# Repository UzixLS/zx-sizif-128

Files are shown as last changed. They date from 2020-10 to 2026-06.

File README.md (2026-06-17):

## Sizif-128

Easy-to-build minimalistic ZX Spectrum clone.

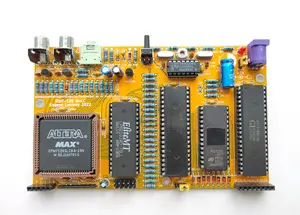
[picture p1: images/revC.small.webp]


[(some random photos)](https://cloud.err200.net/index.php/s/73TR85tYZkMm8Ax?path=%2Fsizif-128)

Specifications:
- CPLD EPM7128SLC84 (128 macrocells)
- Z80 3.5 MHz
- 128K RAM
- AY-3-8910 (YM2149) mono sound
- Pentagon timings
- PAL encoder in CPLD (CRT TVs preferred)
- Intended to build on 9x15 prototyping board, but may be built on manufactured PCB

To modify and compile CPLD firmware you need Quartus 13.0sp1.
To modify schematic and pcb you need Kicad 6 or newer.

### Changelog
* Rev.A - first release. Please note the [errata](pcb/rev.A/ERRATA.txt).
* Rev.B - experimental PCB
    * 74HCU04-based tape input
    * added power LED
    * added reset button
    * removed NMI button
    * C20 replaced by variable variant to tune PAL color signal
* Rev.C
    * 74HCU04-based tape input reverted back to transistor-based
    * unused U6 inputs has been grounded
    * video circuit has been tuned for best colors
    * all pcb tracks are fancy now ;)
* Rev.C1
    * improve tape input sensitivity (thanks to SerOne from zx-pk forum)

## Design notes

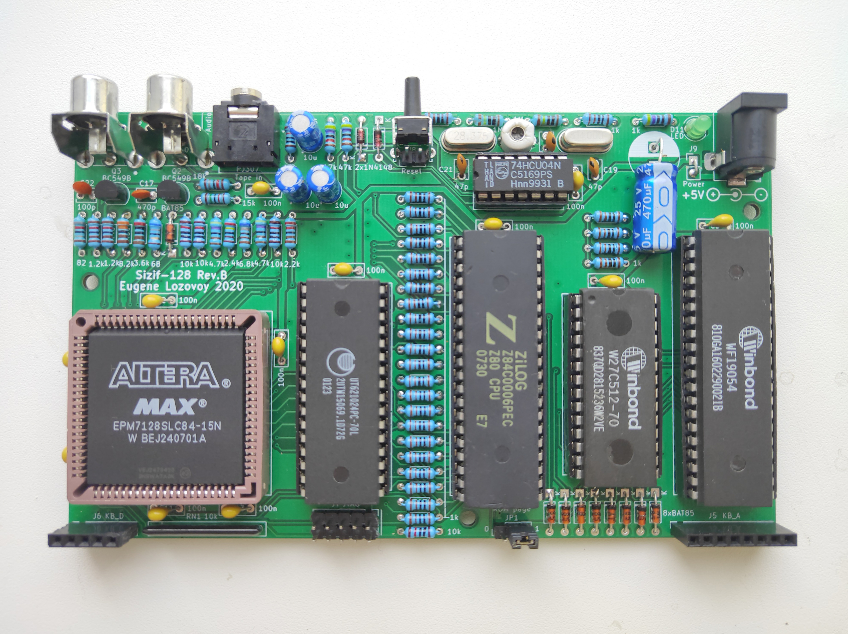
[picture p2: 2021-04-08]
images/revB.jpg

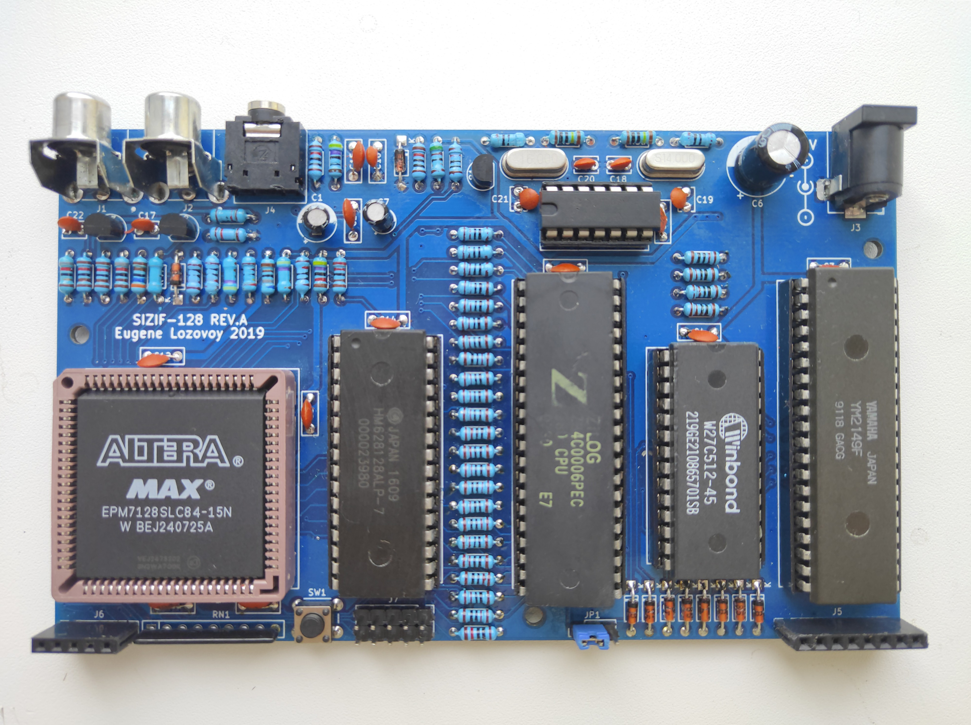
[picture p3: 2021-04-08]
images/revA.jpg

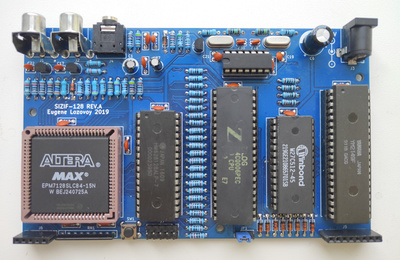
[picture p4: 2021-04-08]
images/revA.small.jpg

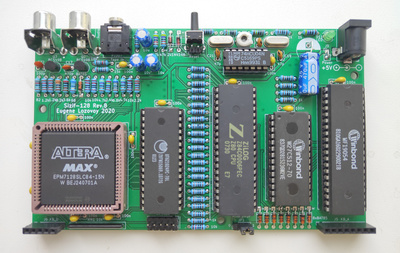
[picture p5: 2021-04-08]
images/revB.small.jpg

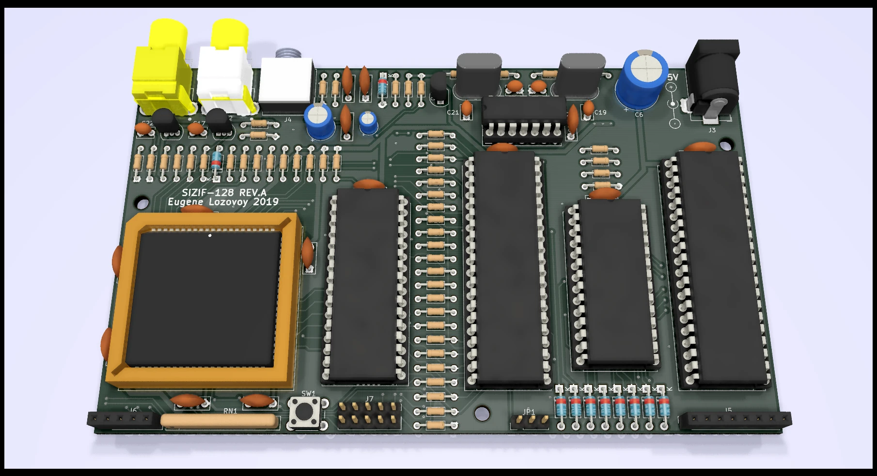
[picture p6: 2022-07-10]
out/pcb3d.rev.A.webp

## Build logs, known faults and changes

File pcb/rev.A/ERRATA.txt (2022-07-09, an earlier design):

To fix compatibility with some LCD TVs:
1. replace 14.318MHz crystal with 14MHz one

To improve RGBI colour balance use these values:
1. R45 6.8k
2. R42 10k
3. R39 18k
4. R46 15k
5. R49 2.4k
6. R50 4.7k

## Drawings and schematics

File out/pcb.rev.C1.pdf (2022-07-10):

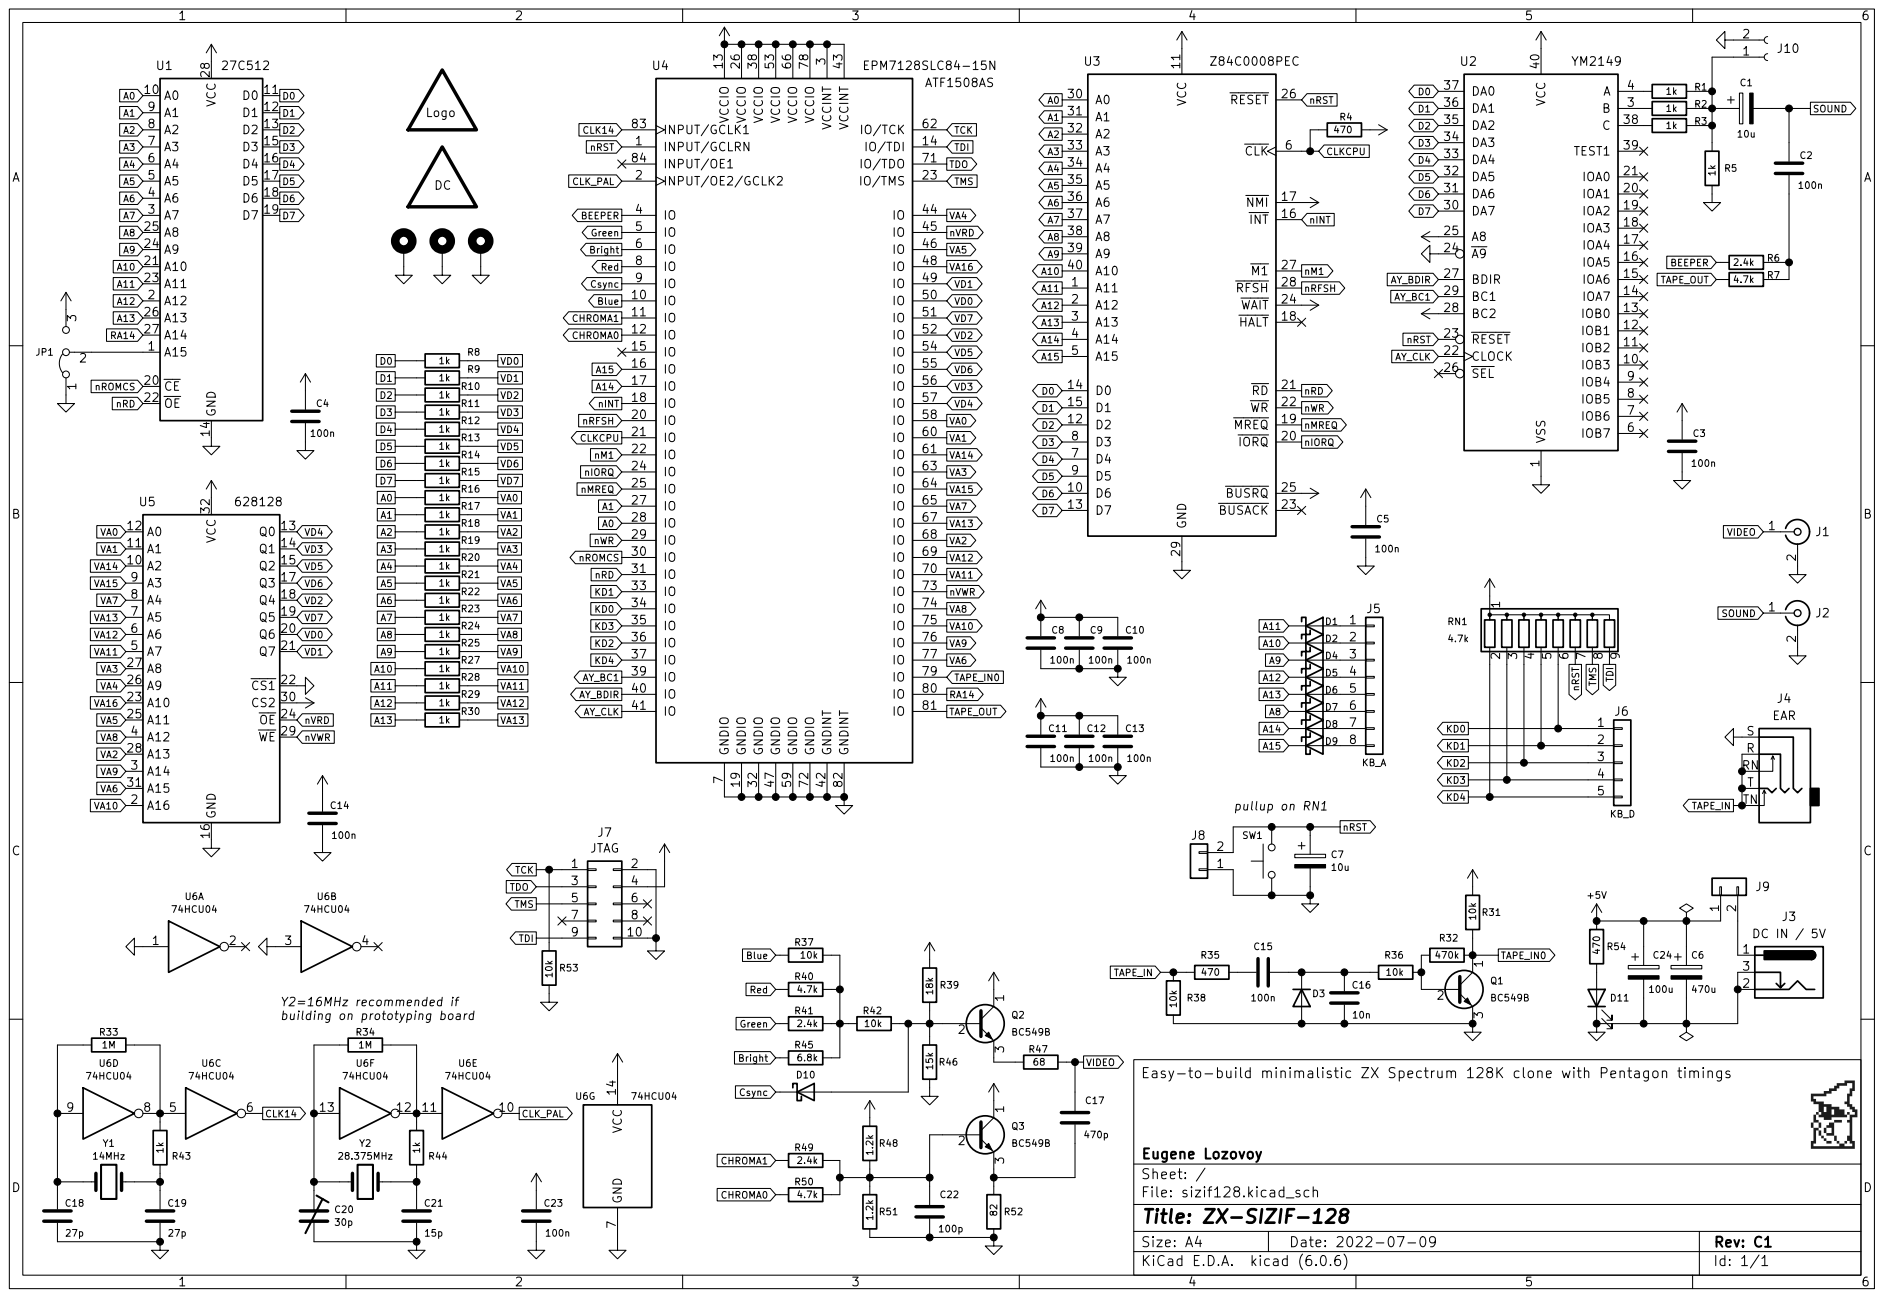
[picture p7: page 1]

7 9 | 8

Y2=16MHz recommended if
building on prototyping board

Easy-to-build minimalistic ZX Spectrum 128K clone with Pentagon timings

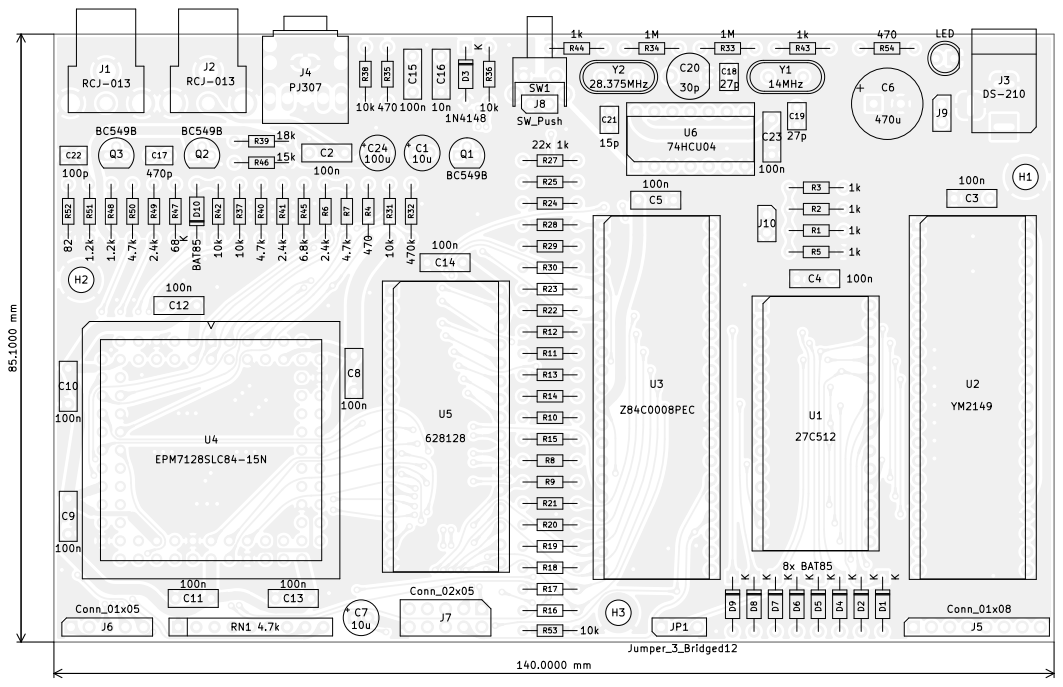
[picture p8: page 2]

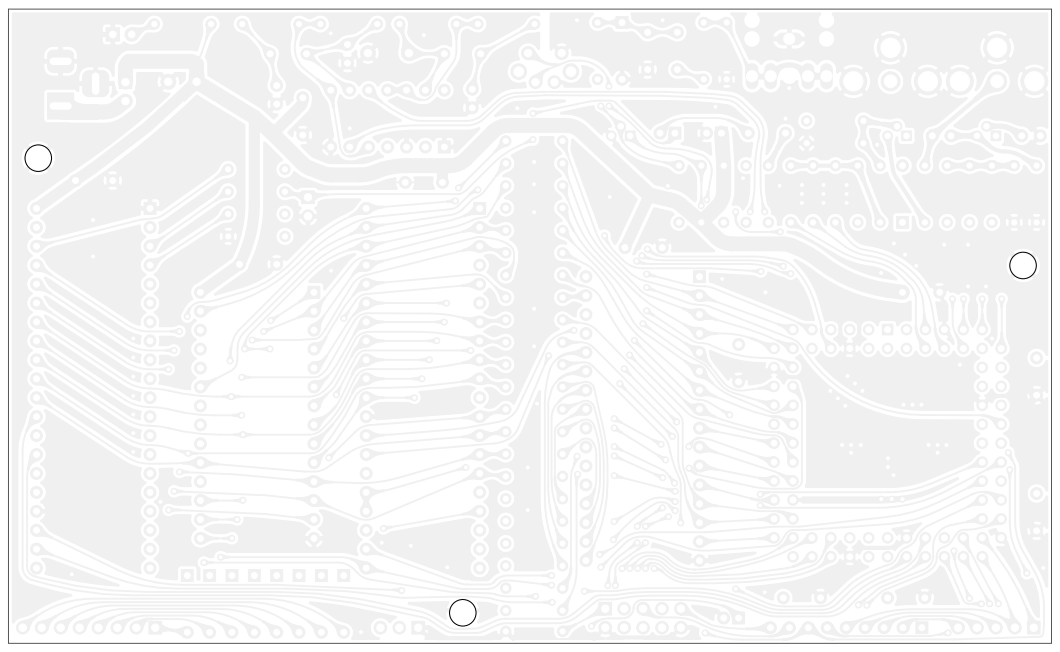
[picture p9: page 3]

Designator | Package | Value | Quantity
C1, C7 | CP_Radial_D5.0mm_P2.00mm | 10u | 2
C2, C3, C4, C5, C8, C9, C10, C11, C12, C13, C14, C15, C23 | C_Disc_D7.0mm_W2.5mm_P5.00mm | 100n | 13
C6 | CP_Radial_D10.0mm_P3.80mm | 470u | 1
C16 | C_Disc_D7.0mm_W2.5mm_P5.00mm | 10n | 1
C17 | C_Disc_D3.8mm_W2.6mm_P2.50mm | 470p | 1
C18, C19 | C_Disc_D3.8mm_W2.6mm_P2.50mm | 27p | 2
C20 | C_Trim_D6.3mm_P5.50mm | 30p | 1
C21 | C_Disc_D3.8mm_W2.6mm_P2.50mm | 15p | 1
C22 | C_Disc_D3.8mm_W2.6mm_P2.50mm | 100p | 1
C24 | CP_Radial_D5.0mm_P2.00mm | 100u | 1
D1, D2, D4, D5, D6, D7, D8, D9, D10 | D_DO-35_SOD27_P7.62mm_Horizontal | BAT85 | 9
D3 | D_DO-35_SOD27_P7.62mm_Horizontal | 1N4148 | 1
D11 | LED_D4.0mm | LED | 1
J1, J2 | CUI_RCJ-013 | RCJ-013 | 2
J3 | BarrelJack_Horizontal | DS-210 | 1
J4 | SWITCHCRAFT_35RAPC4BHN2 | PJ307 | 1
J5 | PinSocket_1x08_P2.54mm_Vertical | Conn_01x08 | 1
J6 | PinSocket_1x05_P2.54mm_Vertical | Conn_01x05 | 1
J7 | PinHeader_2x05_P2.54mm_Vertical | Conn_02x05 | 1
J8, J9 | PinHeader_1x02_P2.54mm_Vertical | Conn_01x02 | 2
J10 | PinSocket_1x02_P2.54mm_Vertical | Conn_01x02_Female | 1
JP1 | PinHeader_1x03_P2.54mm_Vertical | Jumper_3_Bridged12 | 1
Q1, Q2, Q3 | TO-92 | BC549B | 3
R1, R2, R3, R5, R8, R9, R10, R11, R12, R13, R14, R15, R16, R17, R18, R19, R20, R21, R22, R23, R24, R25, R27, R28, R29, R30, R43, R44 | R_Axial_DIN0204_L3.6mm_D1.6mm_P7.62mm_Horizontal | 1k | 28
R4, R35, R54 | R_Axial_DIN0204_L3.6mm_D1.6mm_P7.62mm_Horizontal | 470 | 3
R6, R41, R49 | R_Axial_DIN0204_L3.6mm_D1.6mm_P7.62mm_Horizontal | 2.4k | 3
R7, R40, R50 | R_Axial_DIN0204_L3.6mm_D1.6mm_P7.62mm_Horizontal | 4.7k | 3
R31, R36, R37, R38, R42, R53 | R_Axial_DIN0204_L3.6mm_D1.6mm_P7.62mm_Horizontal | 10k | 6
R32 | R_Axial_DIN0204_L3.6mm_D1.6mm_P7.62mm_Horizontal | 470k | 1
R33, R34 | R_Axial_DIN0204_L3.6mm_D1.6mm_P7.62mm_Horizontal | 1M | 2
R39 | R_Axial_DIN0204_L3.6mm_D1.6mm_P7.62mm_Horizontal | 18k | 1
R45 | R_Axial_DIN0204_L3.6mm_D1.6mm_P7.62mm_Horizontal | 6.8k | 1
R46 | R_Axial_DIN0204_L3.6mm_D1.6mm_P7.62mm_Horizontal | 15k | 1
R47 | R_Axial_DIN0204_L3.6mm_D1.6mm_P7.62mm_Horizontal | 68 | 1
R48, R51 | R_Axial_DIN0204_L3.6mm_D1.6mm_P7.62mm_Horizontal | 1.2k | 2
R52 | R_Axial_DIN0204_L3.6mm_D1.6mm_P7.62mm_Horizontal | 82 | 1
RN1 | R_Array_SIP9 | 4.7k | 1
SW1 | SW_Tactile_SPST_Angled_PTS645Vx83-2LFS | SW_Push | 1
U1 | DIP-28_W15.24mm_Socket | 27C512 | 1
U2 | DIP-40_W15.24mm_Socket | YM2149 | 1
U3 | DIP-40_W15.24mm_Socket | Z84C0008PEC | 1
U4 | PLCC-84_THT-Socket | EPM7128SLC84-15N | 1
U5 | DIP-32_W15.24mm_Socket | 628128 | 1
U6 | DIP-14_W7.62mm_Socket | 74HCU04 | 1
Y1 | Crystal_HC49-U_Vertical | 14MHz | 1
Y2 | Crystal_HC49-U_Vertical | 28.375MHz | 1

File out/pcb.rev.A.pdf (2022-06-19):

# U1 27C512 GND 16 VCC ³²

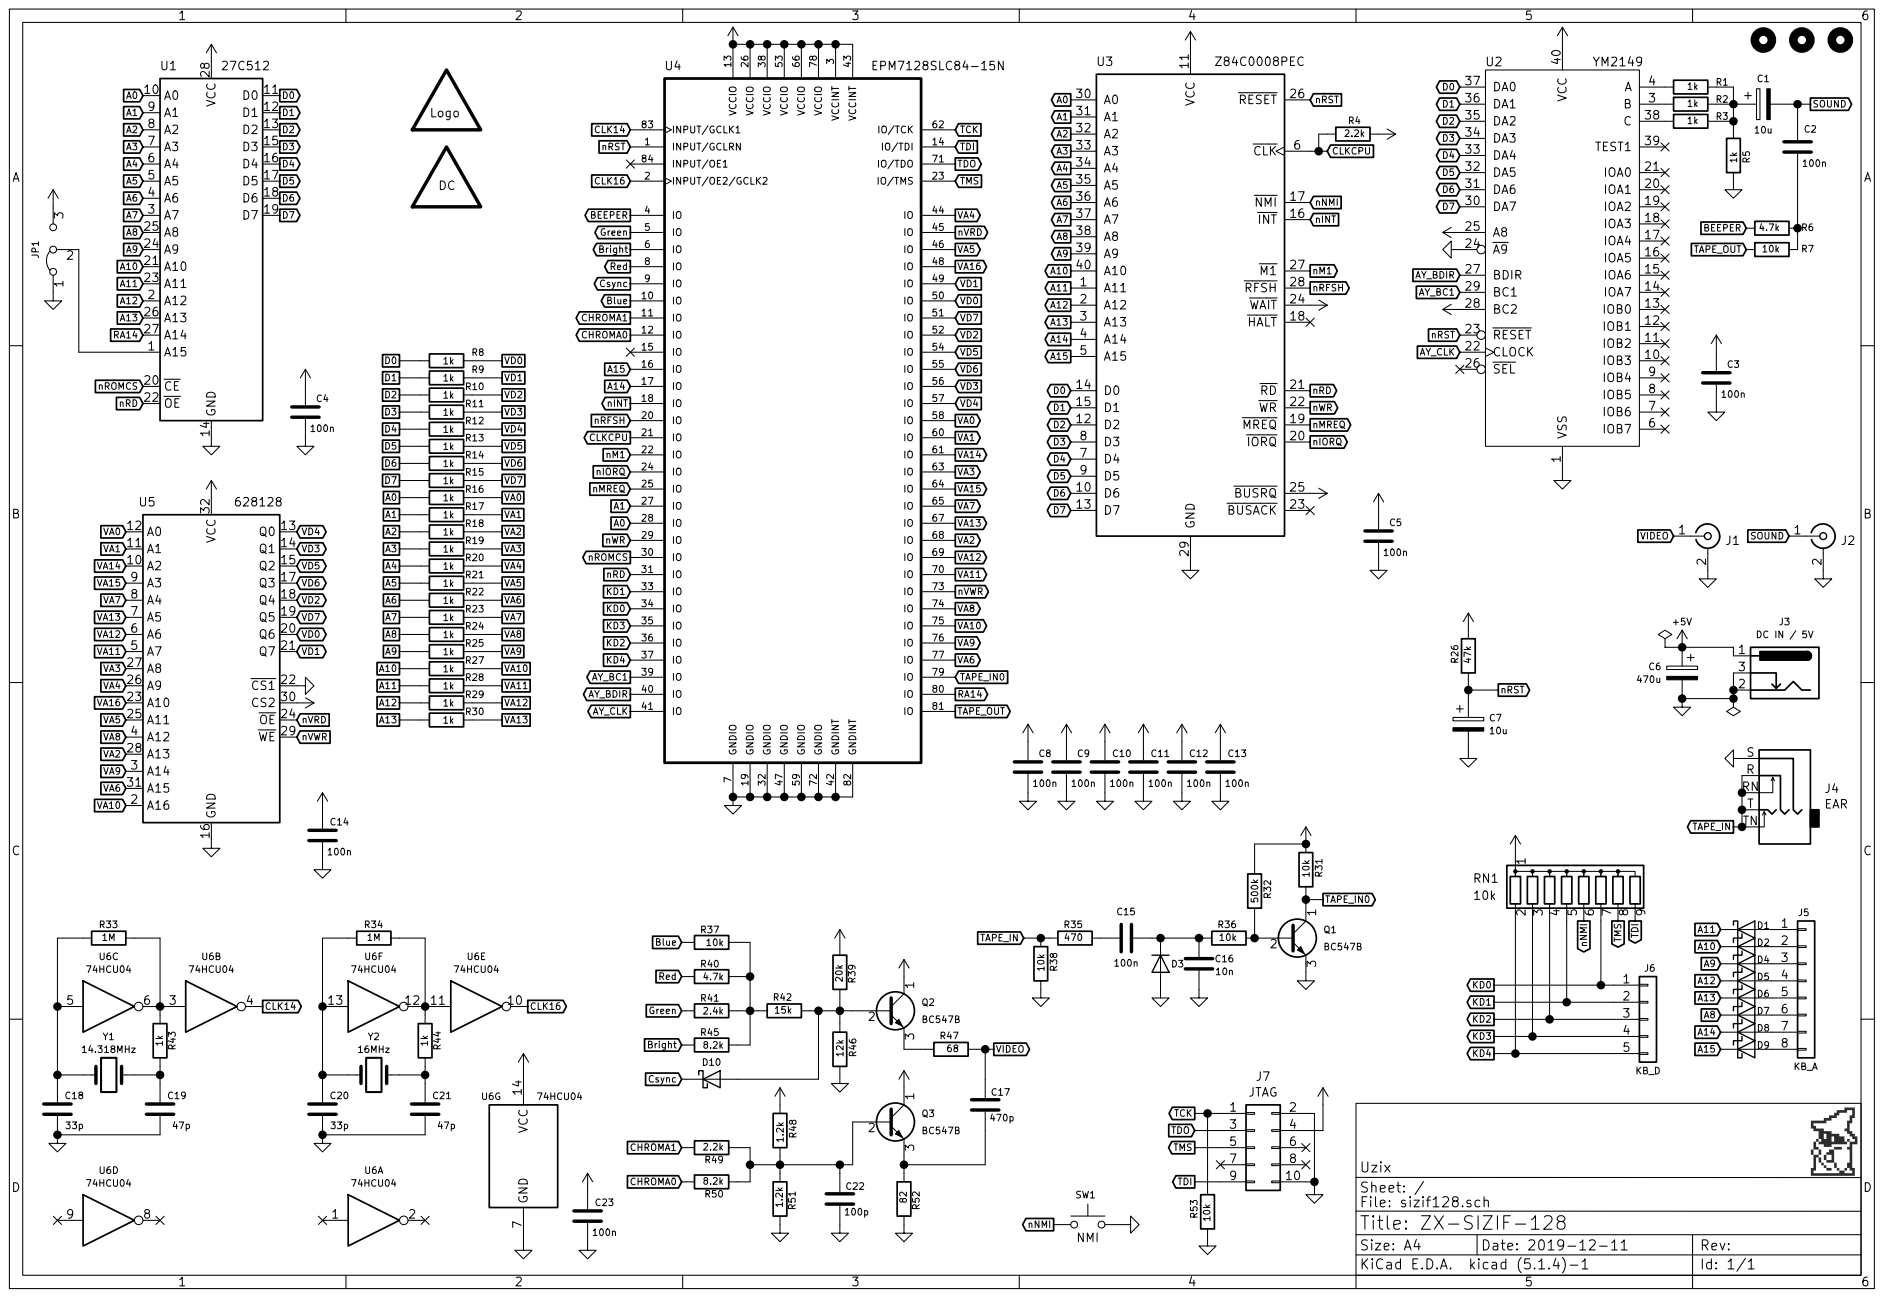
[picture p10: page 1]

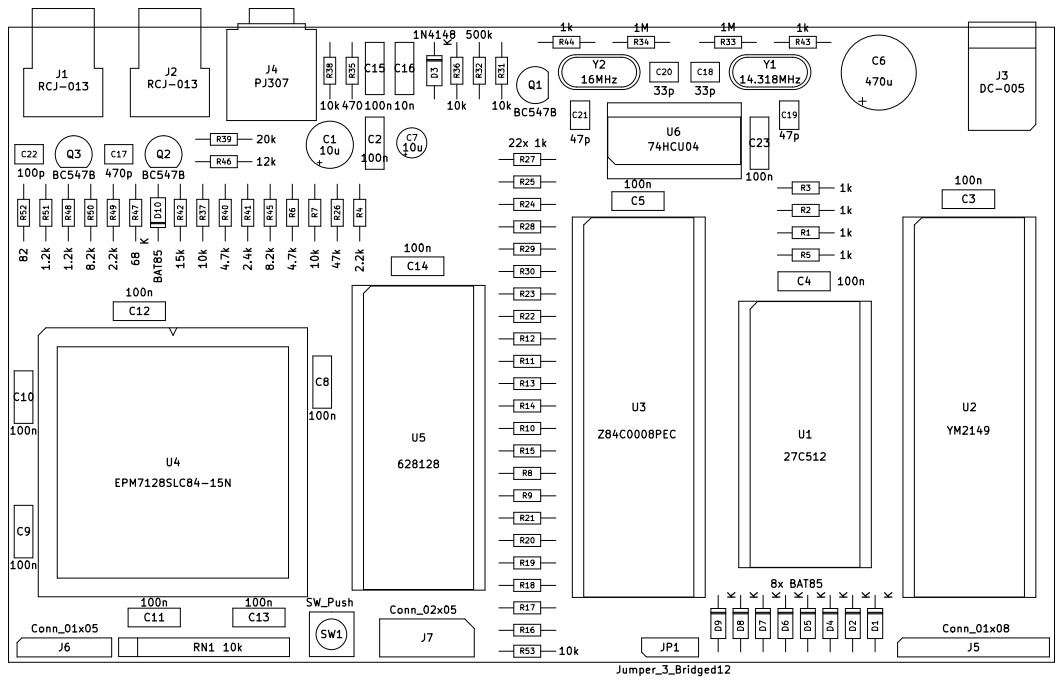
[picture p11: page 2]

Id | Designator | Package | Quantity | Designation
1 | U1 | DIP-28_W15.24mm_Socket | 1 | 27C512
2 | R32 | R_Axial_DIN0204_L3.6mm_D1.6mm_P7.62mm_Horizontal | 1 | 500k
3 | R5,R3,R43,R44,R27,R25,R24,R 28,R29,R30,R23,R22,R12,R11, R13,R14,R10,R15,R8,R9,R21,R 20,R19,R18,R17,R16,R1,R2 | R_Axial_DIN0204_L3.6mm_D1.6mm_P7.62mm_Horizontal | 28 | 1k
4 | R4,R49 | R_Axial_DIN0204_L3.6mm_D1.6mm_P7.62mm_Horizontal | 2 | 2.2k
5 | U4 | PLCC-84_THT-Socket | 1 | EPM7128SLC84-15N
6 | J2,J1 | CUI_RCJ-013 | 2 | RCJ-013
7 | C7 | CP_Radial_D4.0mm_P2.00mm | 1 | 10u
8 | J4 | SWITCHCRAFT_35RAPC4BHN2 | 1 | PJ307
9 | R38,R36,R31,R53,R37,R7 | R_Axial_DIN0204_L3.6mm_D1.6mm_P7.62mm_Horizontal | 6 | 10k
10 | R35 | R_Axial_DIN0204_L3.6mm_D1.6mm_P7.62mm_Horizontal | 1 | 470
11 | Q1,Q3,Q2 | TO-92_Inline | 3 | BC547B
12 | D3 | D_DO-35_SOD27_P7.62mm_Horizontal | 1 | 1N4148
13 | C16 | C_Disc_D7.0mm_W2.5mm_P5.00mm | 1 | 10n
14 | C15,C2,C23,C14,C13,C12,C11, C10,C9,C8,C5,C4,C3 | C_Disc_D7.0mm_W2.5mm_P5.00mm | 13 | 100n
15 | U5 | DIP-32_W15.24mm_Socket | 1 | 628128
16 | J3 | BarrelJack_Horizontal | 1 | DC-005
17 | U3 | DIP-40_W15.24mm_Socket | 1 | Z84C0008PEC
18 | R26 | R_Axial_DIN0204_L3.6mm_D1.6mm_P7.62mm_Horizontal | 1 | 47k
19 | U2 | DIP-40_W15.24mm_Socket | 1 | YM2149
20 | Y2 | Crystal_HC49-U_Vertical | 1 | 16MHz
21 | Y1 | Crystal_HC49-U_Vertical | 1 | 14.318MHz
22 | U6 | DIP-14_W7.62mm_Socket | 1 | 74HCU04
23 | SW1 | SW_PUSH_6mm | 1 | SW_Push
24 | RN1 | R_Array_SIP9 | 1 | 10k
25 | R52 | R_Axial_DIN0204_L3.6mm_D1.6mm_P7.62mm_Horizontal | 1 | 82
26 | R51,R48 | R_Axial_DIN0204_L3.6mm_D1.6mm_P7.62mm_Horizontal | 2 | 1.2k
27 | R50,R45 | R_Axial_DIN0204_L3.6mm_D1.6mm_P7.62mm_Horizontal | 2 | 8.2k
28 | R47 | R_Axial_DIN0204_L3.6mm_D1.6mm_P7.62mm_Horizontal | 1 | 68
29 | R46 | R_Axial_DIN0204_L3.6mm_D1.6mm_P7.62mm_Horizontal | 1 | 12k
30 | R42 | R_Axial_DIN0204_L3.6mm_D1.6mm_P7.62mm_Horizontal | 1 | 15k
31 | R41 | R_Axial_DIN0204_L3.6mm_D1.6mm_P7.62mm_Horizontal | 1 | 2.4k
32 | R40,R6 | R_Axial_DIN0204_L3.6mm_D1.6mm_P7.62mm_Horizontal | 2 | 4.7k
33 | R39 | R_Axial_DIN0204_L3.6mm_D1.6mm_P7.62mm_Horizontal | 1 | 20k
34 | R33,R34 | R_Axial_DIN0204_L3.6mm_D1.6mm_P7.62mm_Horizontal | 2 | 1M
35 | JP1 | PinHeader_1x03_P2.54mm_Vertical | 1 | Jumper_3_Bridged12
36 | J6 | PinSocket_1x05_P2.54mm_Vertical | 1 | Conn_01x05
37 | J5 | PinSocket_1x08_P2.54mm_Vertical | 1 | Conn_01x08
38 | J7 | PinHeader_2x05_P2.54mm_Vertical | 1 | Conn_02x05
39 | D10,D9,D8,D7,D6,D5,D4,D2,D 1 | D_DO-35_SOD27_P7.62mm_Horizontal | 9 | BAT85
40 | C22 | C_Disc_D3.8mm_W2.6mm_P2.50mm | 1 | 100p
41 | C21,C19 | C_Disc_D3.8mm_W2.6mm_P2.50mm | 2 | 47p
42 | C18,C20 | C_Disc_D3.8mm_W2.6mm_P2.50mm | 2 | 33p
43 | C17 | C_Disc_D3.8mm_W2.6mm_P2.50mm | 1 | 470p
44 | C6 | CP_Radial_D10.0mm_P3.80mm | 1 | 470u
45 | C1 | CP_Radial_D6.3mm_P2.50mm | 1 | 10u

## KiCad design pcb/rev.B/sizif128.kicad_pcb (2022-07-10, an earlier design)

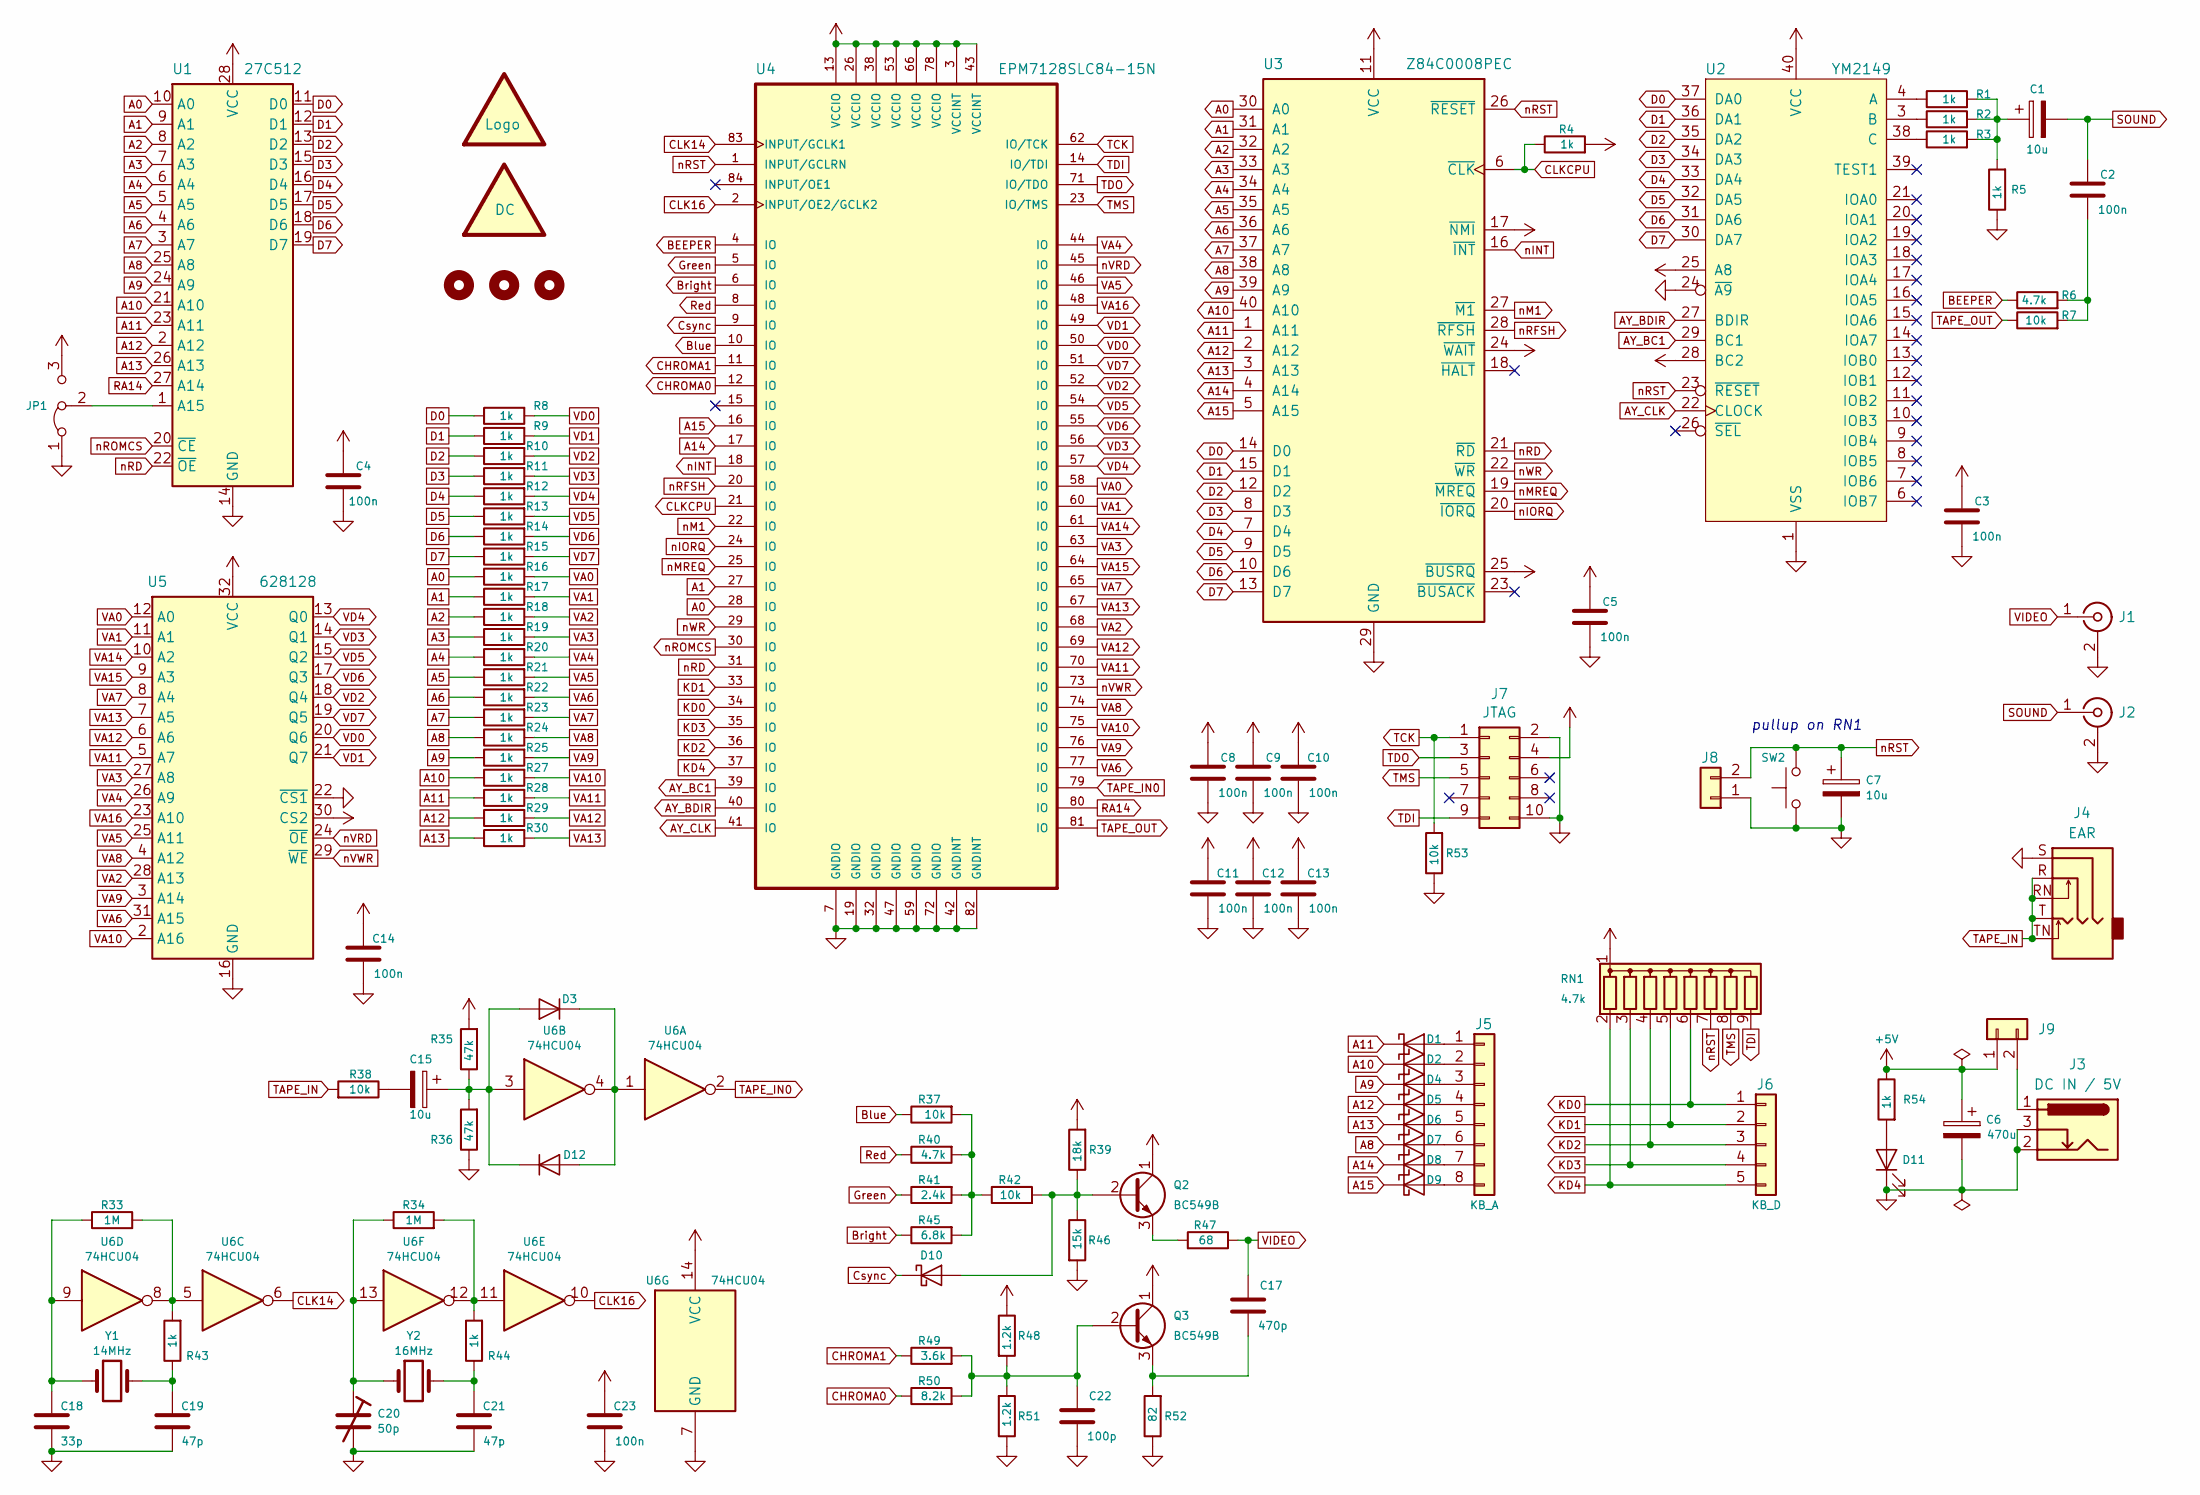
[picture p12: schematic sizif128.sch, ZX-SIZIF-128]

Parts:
C1, C7, C15: 10u; CP_Radial_D5.0mm_P2.00mm
C2, C3, C4, C5, C8, C9, C10, C11, C12, C13, C14, C23: 100n; C_Disc_D7.0mm_W2.5mm_P5.00mm
C6: 470u; CP_Radial_D10.0mm_P3.80mm
C17: 470p; C_Disc_D3.8mm_W2.6mm_P2.50mm
C18: 33p; C_Disc_D3.8mm_W2.6mm_P2.50mm
C19, C21: 47p; C_Disc_D3.8mm_W2.6mm_P2.50mm
C20: 50p; C_Trim_D6.3mm_P5.50mm
C22: 100p; C_Disc_D3.8mm_W2.6mm_P2.50mm
D1, D2, D4, D5, D6, D7, D8, D9, D10: BAT85; D_DO-35_SOD27_P7.62mm_Horizontal
D3, D12: 1N4148; D_DO-35_SOD27_P7.62mm_Horizontal
D11: LED; LED_D4.0mm
H1, H2, H3: MountingHole; MountingHole_3mm
J1, J2: RCJ-013; CUI_RCJ-013
J3: DS-210; BarrelJack_Horizontal
J4: PJ307; SWITCHCRAFT_35RAPC4BHN2
J5: Conn_01x08; PinSocket_1x08_P2.54mm_Vertical
J6: Conn_01x05; PinSocket_1x05_P2.54mm_Vertical
J7: Conn_02x05; PinHeader_2x05_P2.54mm_Vertical
J8, J9: Conn_01x02; PinHeader_1x02_P2.54mm_Vertical
JP1: Jumper_3_Bridged12; PinHeader_1x03_P2.54mm_Vertical
LOGO1: logo; black-mage2
LOGO2: logo; dc_center_positive_big
Q2, Q3: BC549B; TO-92_Inline
R1, R2, R3, R4, R5, R8, R9, R10, R11, R12, R13, R14, R15, R16, R17, R18, R19, R20, R21, R22, R23, R24, R25, R27, R28, R29, R30, R43, R44, R54: 1k; R_Axial_DIN0204_L3.6mm_D1.6mm_P7.62mm_Horizontal
R6, R40: 4.7k; R_Axial_DIN0204_L3.6mm_D1.6mm_P7.62mm_Horizontal
R7, R37, R38, R42, R53: 10k; R_Axial_DIN0204_L3.6mm_D1.6mm_P7.62mm_Horizontal
R33, R34: 1M; R_Axial_DIN0204_L3.6mm_D1.6mm_P7.62mm_Horizontal
R35, R36: 47k; R_Axial_DIN0204_L3.6mm_D1.6mm_P7.62mm_Horizontal
R39: 18k; R_Axial_DIN0204_L3.6mm_D1.6mm_P7.62mm_Horizontal
R41: 2.4k; R_Axial_DIN0204_L3.6mm_D1.6mm_P7.62mm_Horizontal
R45: 6.8k; R_Axial_DIN0204_L3.6mm_D1.6mm_P7.62mm_Horizontal
R46: 15k; R_Axial_DIN0204_L3.6mm_D1.6mm_P7.62mm_Horizontal
R47: 68; R_Axial_DIN0204_L3.6mm_D1.6mm_P7.62mm_Horizontal
R48, R51: 1.2k; R_Axial_DIN0204_L3.6mm_D1.6mm_P7.62mm_Horizontal
R49: 3.6k; R_Axial_DIN0204_L3.6mm_D1.6mm_P7.62mm_Horizontal
R50: 8.2k; R_Axial_DIN0204_L3.6mm_D1.6mm_P7.62mm_Horizontal
R52: 82; R_Axial_DIN0204_L3.6mm_D1.6mm_P7.62mm_Horizontal
RN1: 4.7k; R_Array_SIP9
SW2: SW_Push; SW_Tactile_SPST_Angled_PTS645Vx83-2LFS
U1: 27C512; DIP-28_W15.24mm_Socket
U2: YM2149; DIP-40_W15.24mm_Socket
U3: Z84C0008PEC; DIP-40_W15.24mm_Socket
U4: EPM7128SLC84-15N; PLCC-84_THT-Socket
U5: 628128; DIP-32_W15.24mm_Socket
U6: 74HCU04; DIP-14_W7.62mm_Socket
Y1: 14MHz; Crystal_HC49-U_Vertical
Y2: 16MHz; Crystal_HC49-U_Vertical

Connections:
+5V: C3.2, C4.2, C5.2, C6.1, C8.2, C9.2, C10.2, C11.2, C12.2, C13.2, C14.2, C23.2, J7.4, J9.1, JP1.3 (B), Q2.1 (C), Q3.1 (C), R4.2, R35.2, R39.2, R48.1, R54.1, RN1.1 (common), U1.28 (VCC), U2.25 (A8), U2.28 (BC2), U2.40 (VCC), U3.11 (VCC), U3.17 (~NMI~), U3.24 (~WAIT~), U3.25 (~BUSRQ~), U4.3 (VCCINT), U4.13 (VCCIO), U4.26 (VCCIO), U4.38 (VCCIO), U4.43 (VCCINT), U4.53 (VCCIO), U4.66 (VCCIO), U4.78 (VCCIO), U5.30 (CS2), U5.32 (VCC), U6.14 (VCC)
A0: R16.1, U1.10 (A0), U3.30 (A0), U4.28 (IO)
A1: R17.1, U1.9 (A1), U3.31 (A1), U4.27 (IO)
A2: R18.1, U1.8 (A2), U3.32 (A2)
A3: R19.1, U1.7 (A3), U3.33 (A3)
A4: R20.1, U1.6 (A4), U3.34 (A4)
A5: R21.1, U1.5 (A5), U3.35 (A5)
A6: R22.1, U1.4 (A6), U3.36 (A6)
A7: R23.1, U1.3 (A7), U3.37 (A7)
A8: D7.1 (K), R24.1, U1.25 (A8), U3.38 (A8)
A9: D4.1 (K), R25.1, U1.24 (A9), U3.39 (A9)
A10: D2.1 (K), R27.1, U1.21 (A10), U3.40 (A10)
A11: D1.1 (K), R28.1, U1.23 (A11), U3.1 (A11)
A12: D5.1 (K), R29.1, U1.2 (A12), U3.2 (A12)
A13: D6.1 (K), R30.1, U1.26 (A13), U3.3 (A13)
A14: D8.1 (K), U3.4 (A14), U4.17 (IO)
A15: D9.1 (K), U3.5 (A15), U4.16 (IO)
AY_BC1: U2.29 (BC1), U4.39 (IO)
AY_BDIR: U2.27 (BDIR), U4.40 (IO)
AY_CLK: U2.22 (CLOCK), U4.41 (IO)
BEEPER: R6.1, U4.4 (IO)
Blue: R37.1, U4.10 (IO)
Bright: R45.1, U4.6 (IO)
CHROMA0: R50.1, U4.12 (IO)
CHROMA1: R49.1, U4.11 (IO)
CLK14: U4.83 (INPUT/GCLK1), U6.6
CLK16: U4.2 (INPUT/OE2/GCLK2), U6.10
CLKCPU: R4.1, U3.6 (~CLK~), U4.21 (IO)
Csync: D10.1 (K), U4.9 (IO)
D0: R8.1, U1.11 (D0), U2.37 (DA0), U3.14 (D0)
D1: R9.1, U1.12 (D1), U2.36 (DA1), U3.15 (D1)
D2: R10.1, U1.13 (D2), U2.35 (DA2), U3.12 (D2)
D3: R11.1, U1.15 (D3), U2.34 (DA3), U3.8 (D3)
D4: R12.1, U1.16 (D4), U2.33 (DA4), U3.7 (D4)
D5: R13.1, U1.17 (D5), U2.32 (DA5), U3.9 (D5)
D6: R14.1, U1.18 (D6), U2.31 (DA6), U3.10 (D6)
D7: R15.1, U1.19 (D7), U2.30 (DA7), U3.13 (D7)
GND: C3.1, C4.1, C5.1, C6.2, C7.2, C8.1, C9.1, C10.1, C11.1, C12.1, C13.1, C14.1, C18.1, C19.1, C20.2, C21.1, C22.2, C23.1, D11.1 (K), J1.2 (Ext), J2.2 (Ext), J3.2, J3.3, J4.S, J7.2, J7.10, J8.1, JP1.1 (A), R5.1, R36.1, R46.2, R51.1, R52.1, R53.1, SW2.1, U1.14 (GND), U2.1 (VSS), U2.24 (~A9~), U3.29 (GND), U4.7 (GNDIO), U4.19 (GNDIO), U4.32 (GNDIO), U4.42 (GNDINT), U4.47 (GNDIO), U4.59 (GNDIO), U4.72 (GNDIO), U4.82 (GNDINT), U5.16 (GND), U5.22 (~CS1), U6.7 (GND)
Green: R41.1, U4.5 (IO)
KD0: J6.1, RN1.6 (R5), U4.34 (IO)
KD1: J6.2, RN1.5 (R4), U4.33 (IO)
KD2: J6.3, RN1.4 (R3), U4.36 (IO)
KD3: J6.4, RN1.3 (R2), U4.35 (IO)
KD4: J6.5, RN1.2 (R1), U4.37 (IO)
unnamed: C1.1, R1.2, R2.2, R3.2, R5.2
unnamed: C2.1, R6.2, R7.2
unnamed: C15.1, D3.2 (A), D12.1 (K), R35.1, R36.2, U6.3
unnamed: C15.2, R38.1
unnamed: C17.1, Q3.3 (E), R52.2
unnamed: C18.2, R33.1, U6.9, Y1.1
unnamed: C19.2, R43.1, Y1.2
unnamed: C20.1, R34.1, U6.13, Y2.1
unnamed: C21.2, R44.1, Y2.2
unnamed: C22.1, Q3.2 (B), R48.2, R49.2, R50.2, R51.2
unnamed: D1.2 (A), J5.1
unnamed: D2.2 (A), J5.2
unnamed: D4.2 (A), J5.3
unnamed: D5.2 (A), J5.4
unnamed: D6.2 (A), J5.5
unnamed: D7.2 (A), J5.6
unnamed: D8.2 (A), J5.7
unnamed: D9.2 (A), J5.8
unnamed: D10.2 (A), Q2.2 (B), R39.1, R42.2, R46.1
unnamed: D11.2 (A), R54.2
unnamed: D3.1 (K), D12.2 (A), U6.1, U6.4
unnamed: J3.1, J9.2
unnamed: JP1.2 (C), U1.1 (A15)
unnamed: Q2.3 (E), R47.2
unnamed: R1.1, U2.4 (A)
unnamed: R2.1, U2.3 (B)
unnamed: R3.1, U2.38 (C)
unnamed: R33.2, R43.2, U6.5, U6.8
unnamed: R34.2, R44.2, U6.11, U6.12
unnamed: R37.2, R40.2, R41.2, R42.1, R45.2
RA14: U1.27 (A14), U4.80 (IO)
Red: R40.1, U4.8 (IO)
SOUND: C1.2, C2.2, J2.1 (In)
TAPE_IN: J4.R, J4.RN, J4.T, J4.TN, R38.2
TAPE_IN0: U4.79 (IO), U6.2
TAPE_OUT: R7.1, U4.81 (IO)
TCK: J7.1, R53.2, U4.62 (IO/TCK)
TDI: J7.9, RN1.9 (R8), U4.14 (IO/TDI)
TDO: J7.3, U4.71 (IO/TDO)
TMS: J7.5, RN1.8 (R7), U4.23 (IO/TMS)
VA0: R16.2, U4.58 (IO), U5.12 (A0)
VA1: R17.2, U4.60 (IO), U5.11 (A1)
VA2: R18.2, U4.68 (IO), U5.28 (A13)
VA3: R19.2, U4.63 (IO), U5.27 (A8)
VA4: R20.2, U4.44 (IO), U5.26 (A9)
VA5: R21.2, U4.46 (IO), U5.25 (A11)
VA6: R22.2, U4.77 (IO), U5.31 (A15)
VA7: R23.2, U4.65 (IO), U5.8 (A4)
VA8: R24.2, U4.74 (IO), U5.4 (A12)
VA9: R25.2, U4.76 (IO), U5.3 (A14)
VA10: R27.2, U4.75 (IO), U5.2 (A16)
VA11: R28.2, U4.70 (IO), U5.5 (A7)
VA12: R29.2, U4.69 (IO), U5.6 (A6)
VA13: R30.2, U4.67 (IO), U5.7 (A5)
VA14: U4.61 (IO), U5.10 (A2)
VA15: U4.64 (IO), U5.9 (A3)
VA16: U4.48 (IO), U5.23 (A10)
VD0: R8.2, U4.50 (IO), U5.20 (Q6)
VD1: R9.2, U4.49 (IO), U5.21 (Q7)
VD2: R10.2, U4.52 (IO), U5.18 (Q4)
VD3: R11.2, U4.56 (IO), U5.14 (Q1)
VD4: R12.2, U4.57 (IO), U5.13 (Q0)
VD5: R13.2, U4.54 (IO), U5.15 (Q2)
VD6: R14.2, U4.55 (IO), U5.17 (Q3)
VD7: R15.2, U4.51 (IO), U5.19 (Q5)
VIDEO: C17.2, J1.1 (In), R47.1
nINT: U3.16 (~INT~), U4.18 (IO)
nIORQ: U3.20 (~IORQ~), U4.24 (IO)
nM1: U3.27 (~M1~), U4.22 (IO)
nMREQ: U3.19 (~MREQ~), U4.25 (IO)
nRD: U1.22 (~OE), U3.21 (~RD~), U4.31 (IO)
nRFSH: U3.28 (~RFSH~), U4.20 (IO)
nROMCS: U1.20 (~CE), U4.30 (IO)
nRST: C7.1, J8.2, RN1.7 (R6), SW2.2, U2.23 (~RESET~), U3.26 (~RESET~), U4.1 (INPUT/GCLRN)
nVRD: U4.45 (IO), U5.24 (~OE)
nVWR: U4.73 (IO), U5.29 (~WE)
nWR: U3.22 (~WR~), U4.29 (IO)

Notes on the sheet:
pullup on RN1

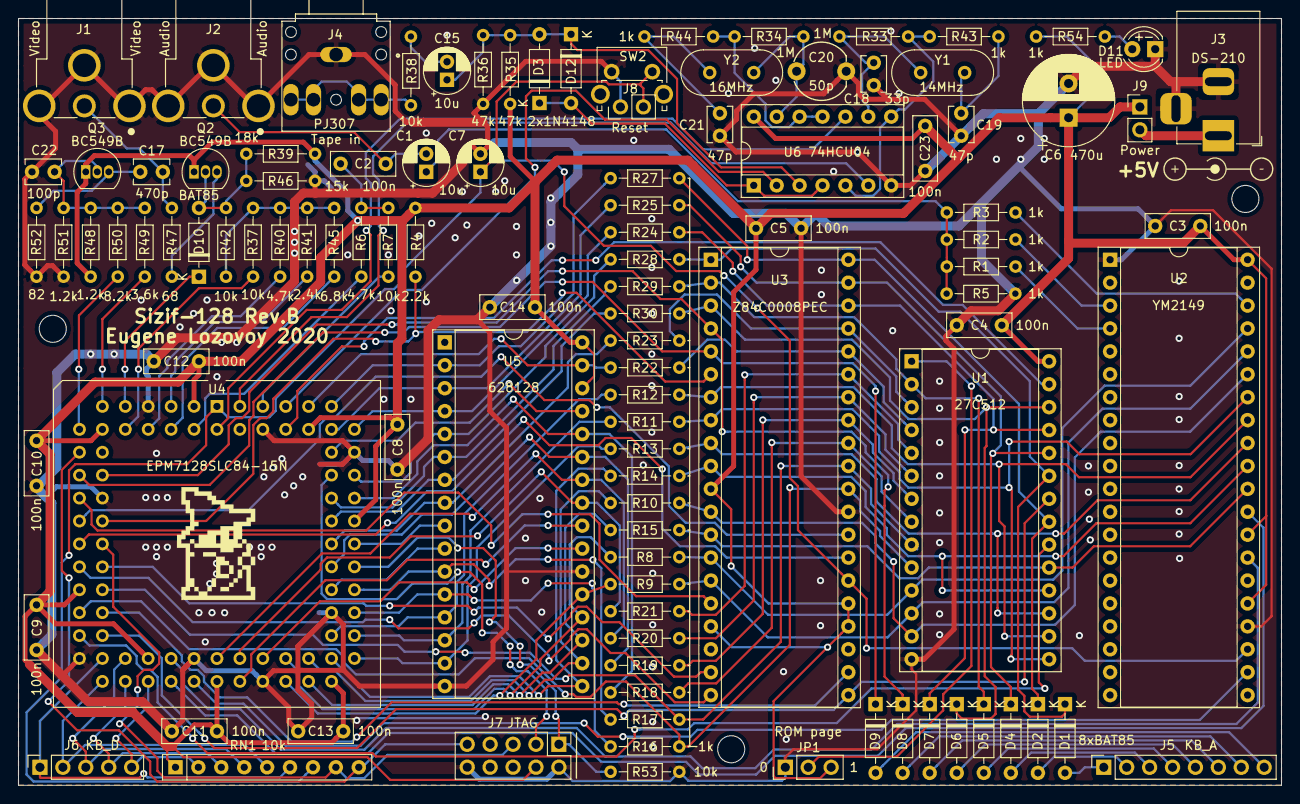
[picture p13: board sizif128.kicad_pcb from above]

Board: 2 copper layers, 140.0 x 85.0 mm, 112 parts (0 on the bottom side), 121 nets.

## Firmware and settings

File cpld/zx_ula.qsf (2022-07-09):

# -------------------------------------------------------------------------- #
#
# Copyright (C) 1991-2009 Altera Corporation
# Your use of Altera Corporation's design tools, logic functions 
# and other software and tools, and its AMPP partner logic 
# functions, and any output files from any of the foregoing 
# (including device programming or simulation files), and any 
# associated documentation or information are expressly subject 
# to the terms and conditions of the Altera Program License 
# Subscription Agreement, Altera MegaCore Function License 
# Agreement, or other applicable license agreement, including, 
# without limitation, that your use is for the sole purpose of 
# programming logic devices manufactured by Altera and sold by 
# Altera or its authorized distributors.  Please refer to the 
# applicable agreement for further details.
#
# -------------------------------------------------------------------------- #
#
# Quartus II
# Version 9.0 Build 235 06/17/2009 Service Pack 2 SJ Web Edition
# Date created = 08:15:12  April 28, 2019
#
# -------------------------------------------------------------------------- #
#
# Notes:
#
# 1) The default values for assignments are stored in the file:
#		zx_ula_assignment_defaults.qdf
#    If this file doesn't exist, see file:
#		assignment_defaults.qdf
#
# 2) Altera recommends that you do not modify this file. This
#    file is updated automatically by the Quartus II software
#    and any changes you make may be lost or overwritten.
#
# -------------------------------------------------------------------------- #


set_global_assignment -name FAMILY MAX7000S
set_global_assignment -name DEVICE "EPM7128SLC84-15"
set_global_assignment -name TOP_LEVEL_ENTITY zx_ula
set_global_assignment -name ORIGINAL_QUARTUS_VERSION "9.0 SP2"
set_global_assignment -name PROJECT_CREATION_TIME_DATE "08:15:12  APRIL 28, 2019"
set_global_assignment -name LAST_QUARTUS_VERSION "13.0 SP1"
set_global_assignment -name USE_GENERATED_PHYSICAL_CONSTRAINTS OFF -section_id eda_blast_fpga
set_global_assignment -name DEVICE_FILTER_SPEED_GRADE 15
set_global_assignment -name MIN_CORE_JUNCTION_TEMP 0
set_global_assignment -name MAX_CORE_JUNCTION_TEMP 85
set_global_assignment -name MAX7000_DEVICE_IO_STANDARD TTL
set_location_assignment PIN_10 -to b
set_location_assignment PIN_4 -to beeper
set_location_assignment PIN_83 -to clk14
set_location_assignment PIN_21 -to clkcpu
set_location_assignment PIN_5 -to g
set_location_assignment PIN_18 -to n_int
set_location_assignment PIN_24 -to n_iorq
set_location_assignment PIN_22 -to n_m1
set_location_assignment PIN_25 -to n_mreq
set_location_assignment PIN_31 -to n_rd
set_location_assignment PIN_20 -to n_rfsh
set_location_assignment PIN_30 -to n_romcs
set_location_assignment PIN_45 -to n_vrd
set_location_assignment PIN_73 -to n_vwr
set_location_assignment PIN_29 -to n_wr
set_location_assignment PIN_8 -to r
set_location_assignment PIN_1 -to rst_n
set_location_assignment PIN_81 -to tape_out
set_location_assignment PIN_48 -to va[16]
set_location_assignment PIN_64 -to va[15]
set_location_assignment PIN_61 -to va[14]
set_location_assignment PIN_67 -to va[13]
set_location_assignment PIN_69 -to va[12]
set_location_assignment PIN_70 -to va[11]
set_location_assignment PIN_75 -to va[10]
set_location_assignment PIN_76 -to va[9]
set_location_assignment PIN_74 -to va[8]
set_location_assignment PIN_65 -to va[7]
set_location_assignment PIN_77 -to va[6]
set_location_assignment PIN_46 -to va[5]
set_location_assignment PIN_44 -to va[4]
set_location_assignment PIN_63 -to va[3]
set_location_assignment PIN_68 -to va[2]
set_location_assignment PIN_60 -to va[1]
set_location_assignment PIN_58 -to va[0]
set_location_assignment PIN_51 -to vd[7]
set_location_assignment PIN_55 -to vd[6]
set_location_assignment PIN_54 -to vd[5]
set_location_assignment PIN_57 -to vd[4]
set_location_assignment PIN_56 -to vd[3]
set_location_assignment PIN_52 -to vd[2]
set_location_assignment PIN_49 -to vd[1]
set_location_assignment PIN_50 -to vd[0]
set_global_assignment -name VERILOG_INPUT_VERSION SYSTEMVERILOG_2005
set_global_assignment -name VERILOG_SHOW_LMF_MAPPING_MESSAGES OFF
set_global_assignment -name MAX7000_OPTIMIZATION_TECHNIQUE BALANCED
set_global_assignment -name FMAX_REQUIREMENT "14 MHz"
set_global_assignment -name FMAX_REQUIREMENT "14 MHz" -section_id clk14
set_location_assignment PIN_6 -to i
set_instance_assignment -name CLOCK_SETTINGS clk14 -to clk14
set_instance_assignment -name CLOCK_SETTINGS clkcpu -to clkcpu
set_location_assignment PIN_28 -to a0
set_location_assignment PIN_27 -to a1
set_location_assignment PIN_17 -to a14
set_location_assignment PIN_16 -to a15
set_global_assignment -name AUTO_RESOURCE_SHARING OFF
set_global_assignment -name AUTO_LCELL_INSERTION OFF
set_location_assignment PIN_9 -to csync
set_location_assignment PIN_2 -to clkpal
set_location_assignment PIN_11 -to chroma[1]
set_location_assignment PIN_12 -to chroma[0]
set_location_assignment PIN_33 -to kd[1]
set_location_assignment PIN_34 -to kd[0]
set_location_assignment PIN_35 -to kd[3]
set_location_assignment PIN_36 -to kd[2]
set_location_assignment PIN_37 -to kd[4]
set_location_assignment PIN_39 -to ay_bc1
set_location_assignment PIN_40 -to ay_bdir
set_location_assignment PIN_41 -to ay_clk
set_location_assignment PIN_79 -to tape_in
set_location_assignment PIN_80 -to ra14
set_global_assignment -name BASED_ON_CLOCK_SETTINGS clk14 -section_id clkcpu
set_global_assignment -name MULTIPLY_BASE_CLOCK_PERIOD_BY 2 -section_id clkcpu
set_global_assignment -name OPTIMIZE_HOLD_TIMING OFF
set_global_assignment -name FITTER_EFFORT "STANDARD FIT"
set_global_assignment -name AUTO_TURBO_BIT ON
set_global_assignment -name OPTIMIZE_IOC_REGISTER_PLACEMENT_FOR_TIMING NORMAL
set_global_assignment -name SAVE_DISK_SPACE OFF
set_global_assignment -name FIT_ONLY_ONE_ATTEMPT OFF
set_global_assignment -name SLOW_SLEW_RATE OFF
set_global_assignment -name PROJECT_OUTPUT_DIRECTORY output/
set_global_assignment -name SYNTH_TIMING_DRIVEN_SYNTHESIS OFF
set_global_assignment -name SDC_FILE clocks.sdc
set_global_assignment -name VERILOG_FILE chroma_gen.v
set_global_assignment -name VERILOG_FILE top.v

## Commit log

2020-04-19 add pcb
    [sizif128.kicad_pcb, sizif128.sch]
2020-04-19 add delivered files (gerbers, firmware binary, etc)
2020-08-15 update firmware
    1. quartus 13 may be used for build now;
    2. fix small border offset;
    3. fix too fast flashing with attribute bit 7.
    [zx_ula.qsf]
2020-10-12 pcb: move old files to rev.A folder
    [sizif128.kicad_pcb, sizif128.sch]
2020-10-12 git: fix CRLF
    [sizif128.kicad_pcb, sizif128.sch]
2020-10-12 pcb rev.A: add errata
2020-10-26 cpld: do not stop screen render on reset
    [zx_ula.qsf]
2020-10-29 pcb rev.A: add R49=3.6k to errata
2021-04-08 gitignore, gitattributes: add kicad 6 entries
2022-07-10 add pcb rev.B
    [sizif128.kicad_pcb, sizif128.sch]
2022-07-10 add pcb rev.C
    [sizif128.kicad_sch]
2022-07-10 add pcb rev.C1
    [sizif128.kicad_sch]
2022-07-10 add pcb rev.C1 gerbers, pdf, etc...
